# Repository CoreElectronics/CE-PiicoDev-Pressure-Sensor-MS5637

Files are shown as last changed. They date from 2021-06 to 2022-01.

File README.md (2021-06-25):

# PiicoDev® Pressure Sensor MS5637

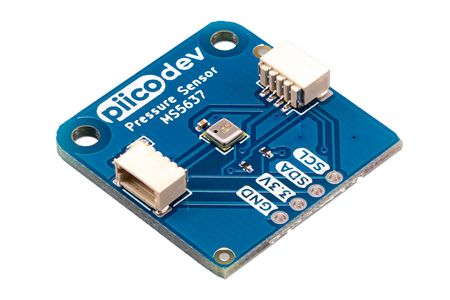
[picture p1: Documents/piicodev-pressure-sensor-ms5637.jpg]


This is the repo for the Core Electronics [PiicoDev Pressure Sensor](https://core-electronics.com.au/catalog/product/view/sku/CE07832).

Our PiicoDev® Pressure Sensor is perfect for measuring barometric pressure or infering altitude from air pressure - the on-board MS5637 is capable of measuring differences as small as 13cm! The accurate, MEMs pressure sensor is very sensitive, factory calibrated, low power and easy to use - forfect for home weather stations, detecting changes in altitude or pneumatic-based control projects.

**Features**

- Accurate air pressure measurements
- PiicoDev connector, compatible with Qwiic and STEMMA QT (3.3V only)
- 2.54mm breakout for breadboarding/prototyping
- Manufactured and [supported](https://core-electronics.com.au/contacts/) in Australia by Core Electronics
- [Getting Started Guides](https://core-electronics.com.au/catalog/product/view/sku/CE07832#guides)

**Technical Specifications**

- I2C address: 0x76
- Dimensions: 25.4x25.4mm
- Mounting Holes: 2x M2.5
- MS5637:
  - Operating range: 300 to 1200 hPa, -40 to 85°C
  - Error band at 25°C: ±2 hPa

## License
This project is open source - please review the LICENSE.md file for further licensing information.

If you have any technical questions, or concerns about licensing, please contact technical support on the [Core Electronics forums](https://forum.core-electronics.com.au/).

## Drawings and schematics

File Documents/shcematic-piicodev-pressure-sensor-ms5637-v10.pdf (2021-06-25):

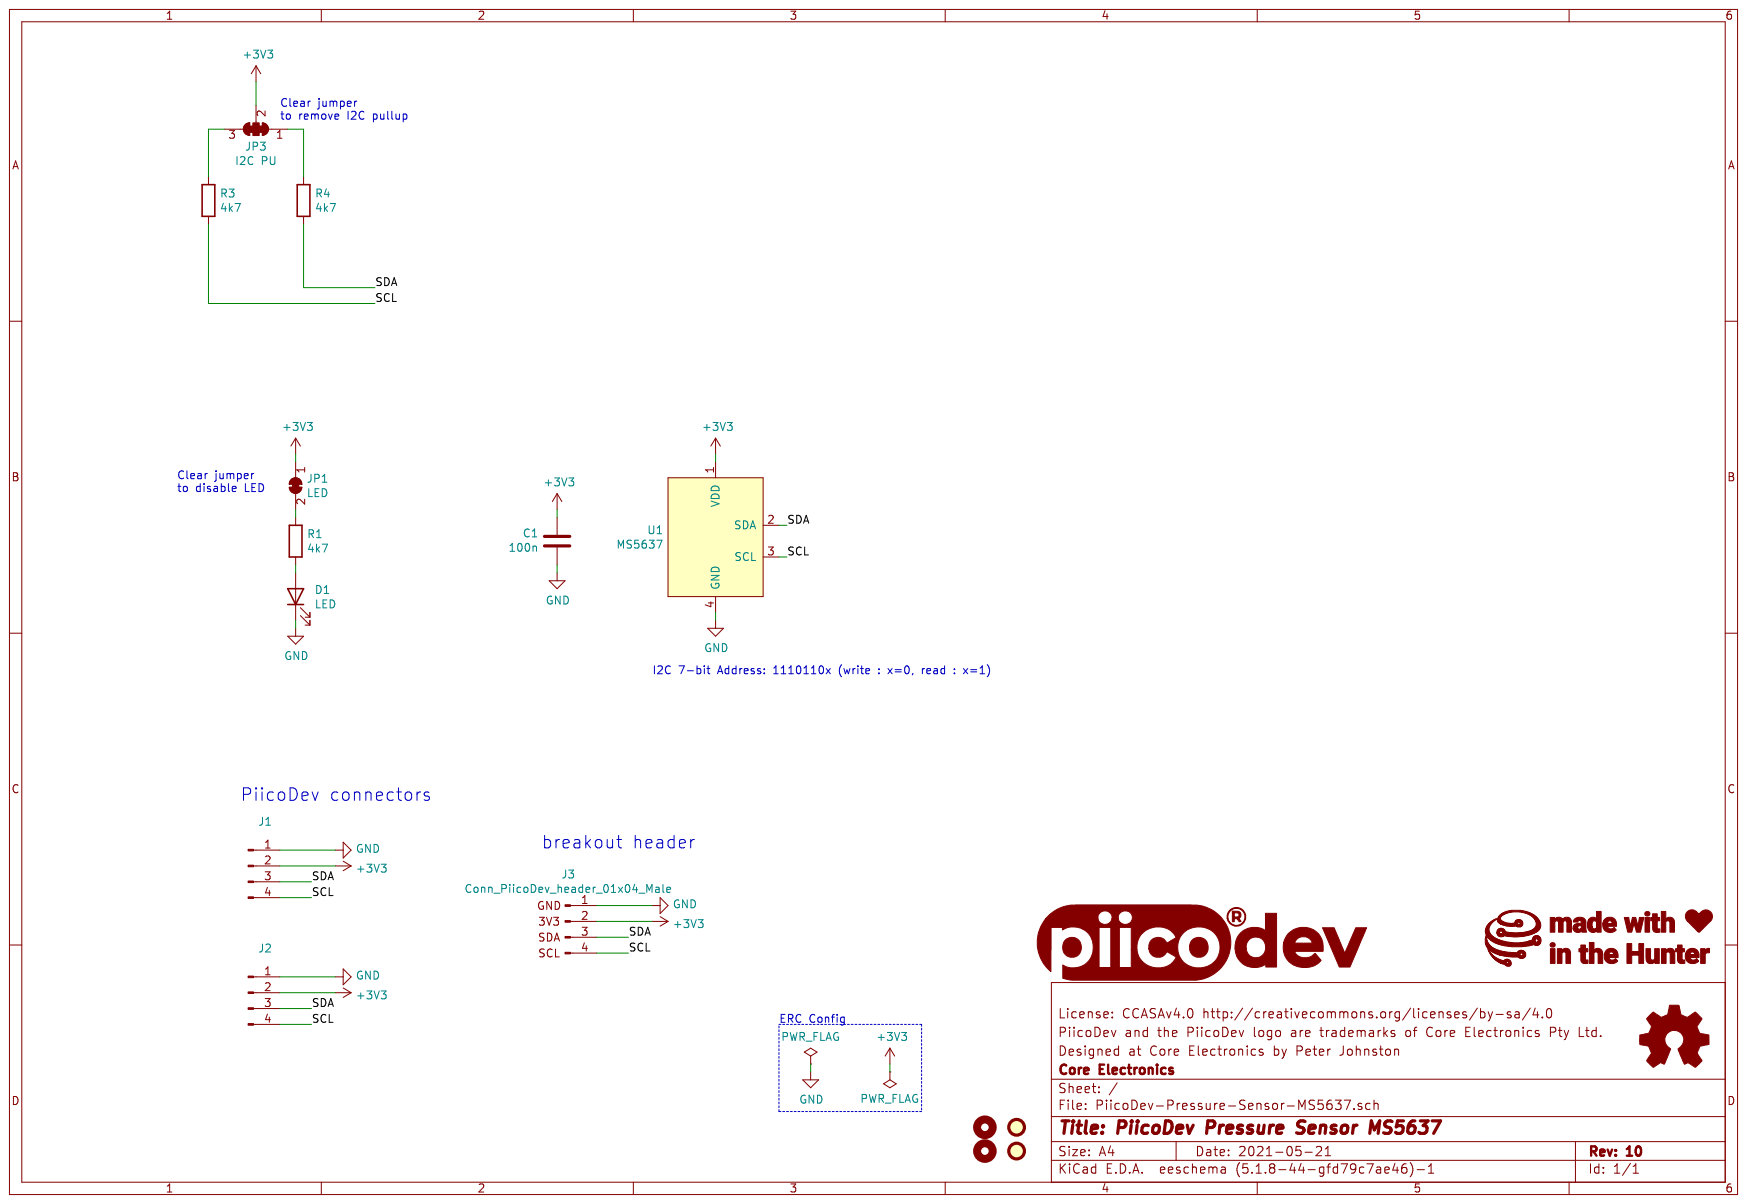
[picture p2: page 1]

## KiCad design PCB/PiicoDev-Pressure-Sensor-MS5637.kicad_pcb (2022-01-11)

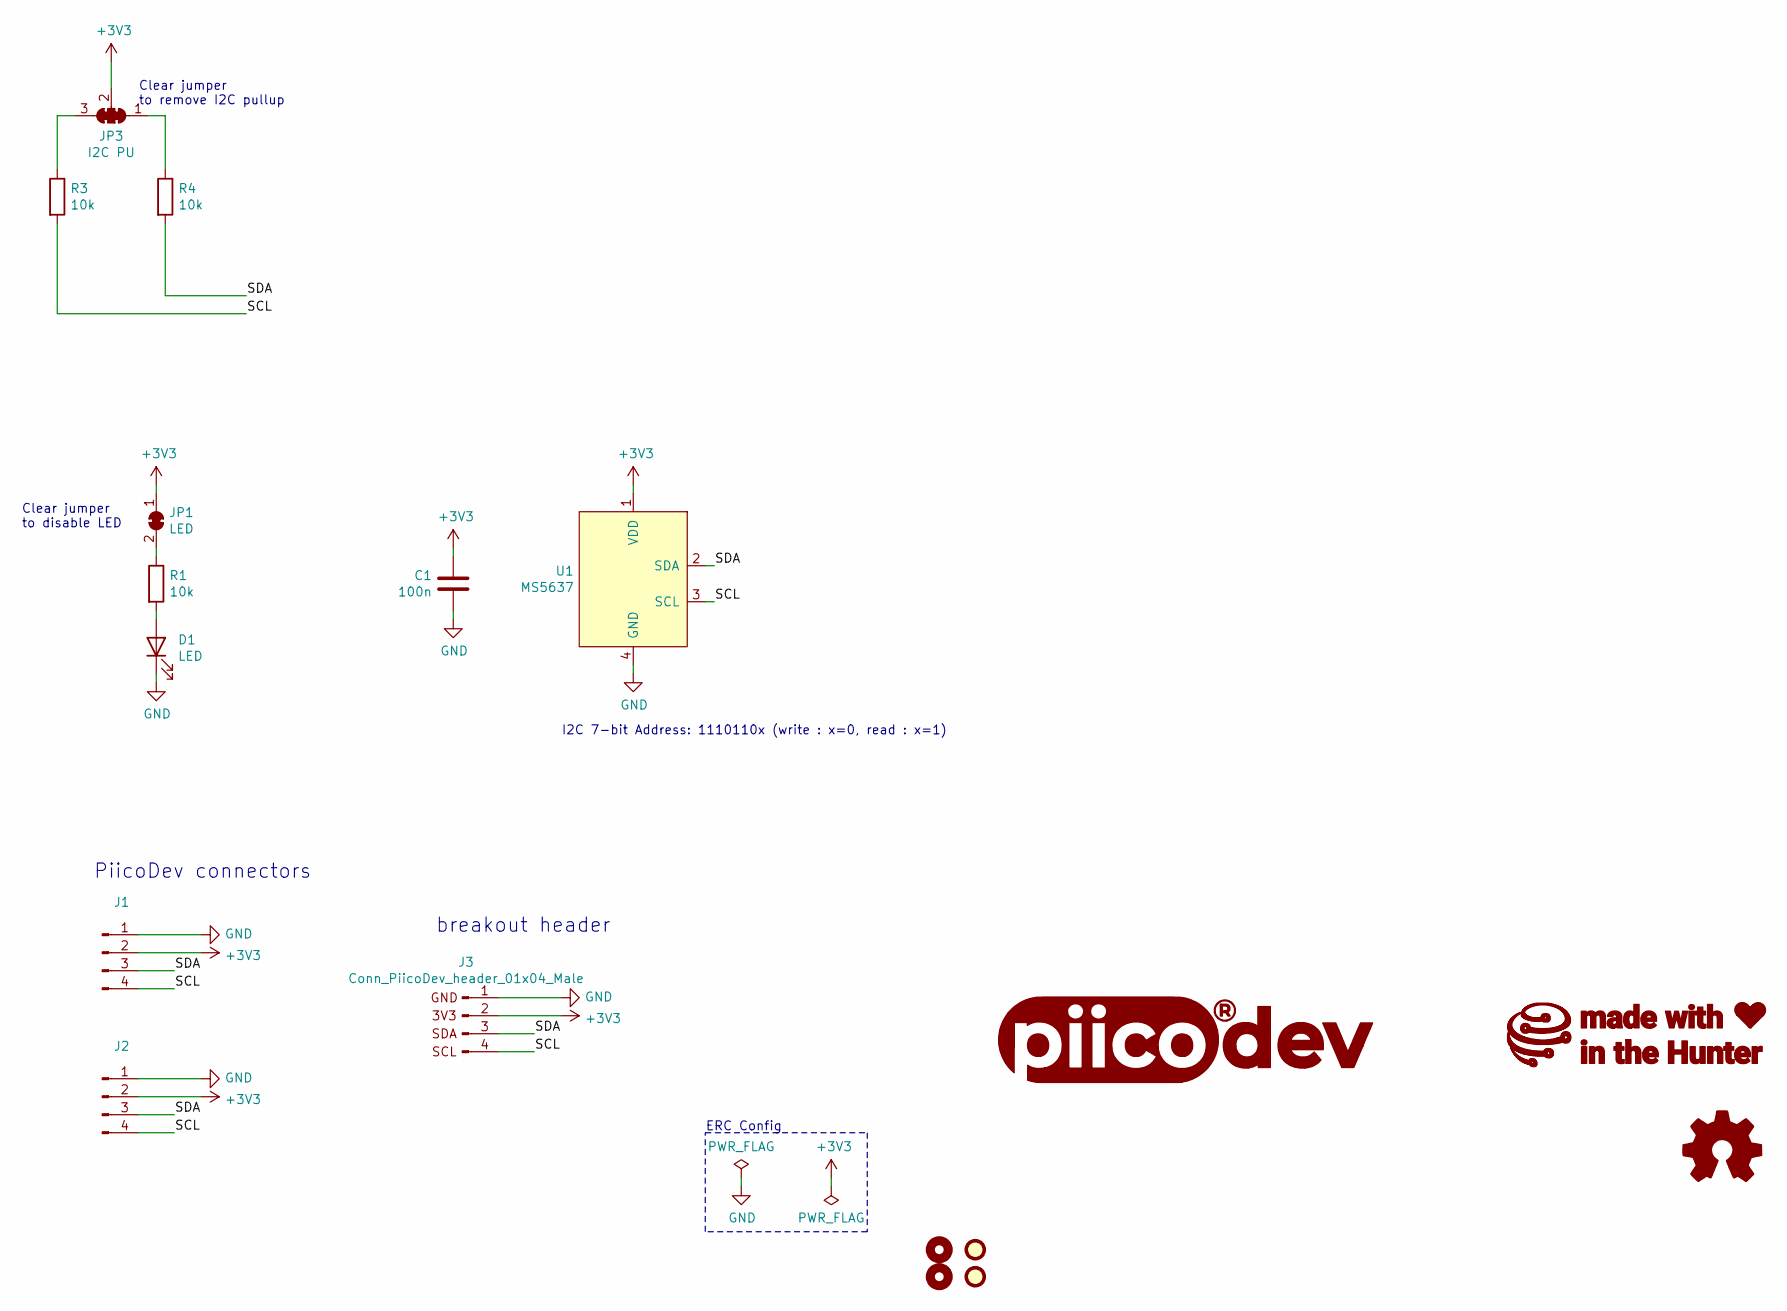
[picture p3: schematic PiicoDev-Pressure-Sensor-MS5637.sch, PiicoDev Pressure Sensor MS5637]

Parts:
C1: 100n; C_0402_1005Metric
D1: LED; LED_0603_1608Metric
FID1, FID2: Fiducial; Fiducial_1mm_Mask2mm
G1: LOGO_CoreElectronics_no-text; CoreElectronics_logo_5mm
G2: LOGO_piico; piicodev_logo_14.2x3.4mm
G3: LOGO_made-with-love; piicodev_logo_14.2x3.4mm
H1, H4: MountingHole; MountingHole_2.7mm_M2.5_PadClearance_1.2
J1, J2: JST_SH_SM04B-SRSS-TB_1x04-1MP_P1.00mm_Horizontal
J3: Conn_PiicoDev_header_01x04_Male; PiicoDev_header_4pin
JP1: LED; SolderJumper-2_P1.3mm_Bridged_RoundedPad1.0x1.5mm
JP3: I2C PU; SolderJumper-3_P1.3mm_Closed_RoundedPad1.0x1.5mm_NumberLabe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
LOGO1: Logo_Open_Hardware_Small; oshw
R1, R3, R4: 10k; R_0402_1005Metric
U1: MS5637; TE_MS5637

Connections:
+3V3: C1.2, J1.2, J2.2, J3.2, JP1.1 (A), JP3.2 (C), U1.1 (VDD)
/SCL: J1.4, J2.4, J3.4, R3.2, U1.3 (SCL)
/SDA: J1.3, J2.3, J3.3, R4.2, U1.2 (SDA)
GND: C1.1, D1.1 (K), J1.1, J2.1, J3.1, U1.4 (GND)
unnamed: D1.2 (A), R1.2
unnamed: JP1.2 (B), R1.1
unnamed: JP3.1 (A), R4.1
unnamed: JP3.3 (B), R3.1

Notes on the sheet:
Clear jumper to disable LED
Clear jumper to remove I2C pullup
PiicoDev connectors
breakout header
I2C 7-bit Address: 1110110x (write : x=0, read : x=1)
ERC Config

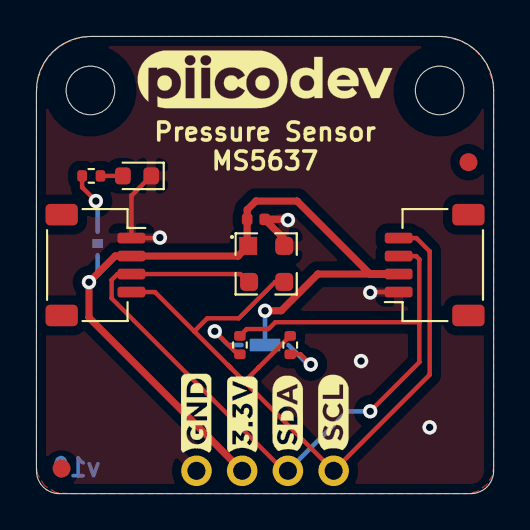
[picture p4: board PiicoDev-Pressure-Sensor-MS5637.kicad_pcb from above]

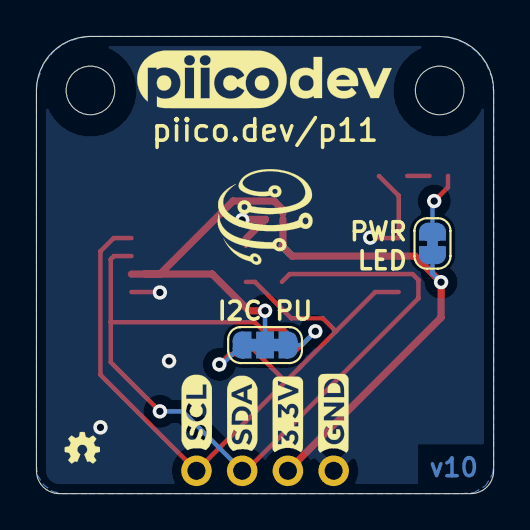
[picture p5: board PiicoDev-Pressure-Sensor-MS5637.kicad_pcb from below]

Board: 2 copper layers, 25.4 x 25.4 mm, 19 parts (6 on the bottom side), 8 nets.

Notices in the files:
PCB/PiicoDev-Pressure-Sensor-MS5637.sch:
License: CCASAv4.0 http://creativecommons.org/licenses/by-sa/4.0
